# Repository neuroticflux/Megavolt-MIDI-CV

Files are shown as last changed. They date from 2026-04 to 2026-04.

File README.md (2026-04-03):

# Megavolt-MIDI-CV
ATmega328-based modular synth MIDI-CV interface

The Megavolt is a MIDI-CV interface featuring two high quality 12-bit CV outputs for note and pitchbend, four 8-bit CV outputs for MIDI CC's, as well as GATE output, two CLOCK outputs and note glide.

12-bit CVs:
CV 1: MIDI note (with glide amount pot)
CV 2: Pitchbend

MIDI NOTE ON triggers the GATE output HIGH. MIDI NOTE OFF triggers it low.

8-bit CVs:
CV 3: CC #01 (Modwheel)
CV 4: CC #04 (Aftertouch/foot controller)
CV 5: CC #16 (General purpose)
CV 6: Velocity

The two CLOCK jacks output 1/1' and 1/16' ticks the from incoming MIDI clock.

A note stack of 4 notes allows several keys to be held down in succession and released to return to the previous note in the stack, allowing for fast playing of arpeggios etc.

The interface is made to hook up to a PSU delivering +/-15V as well as +5V (Synthesizers.com standard).
Current draw untested.

TODO:

- Eurorack compatibility
- Detect MIDI channel on first incoming message
- Reverse voltage protection diodes on input

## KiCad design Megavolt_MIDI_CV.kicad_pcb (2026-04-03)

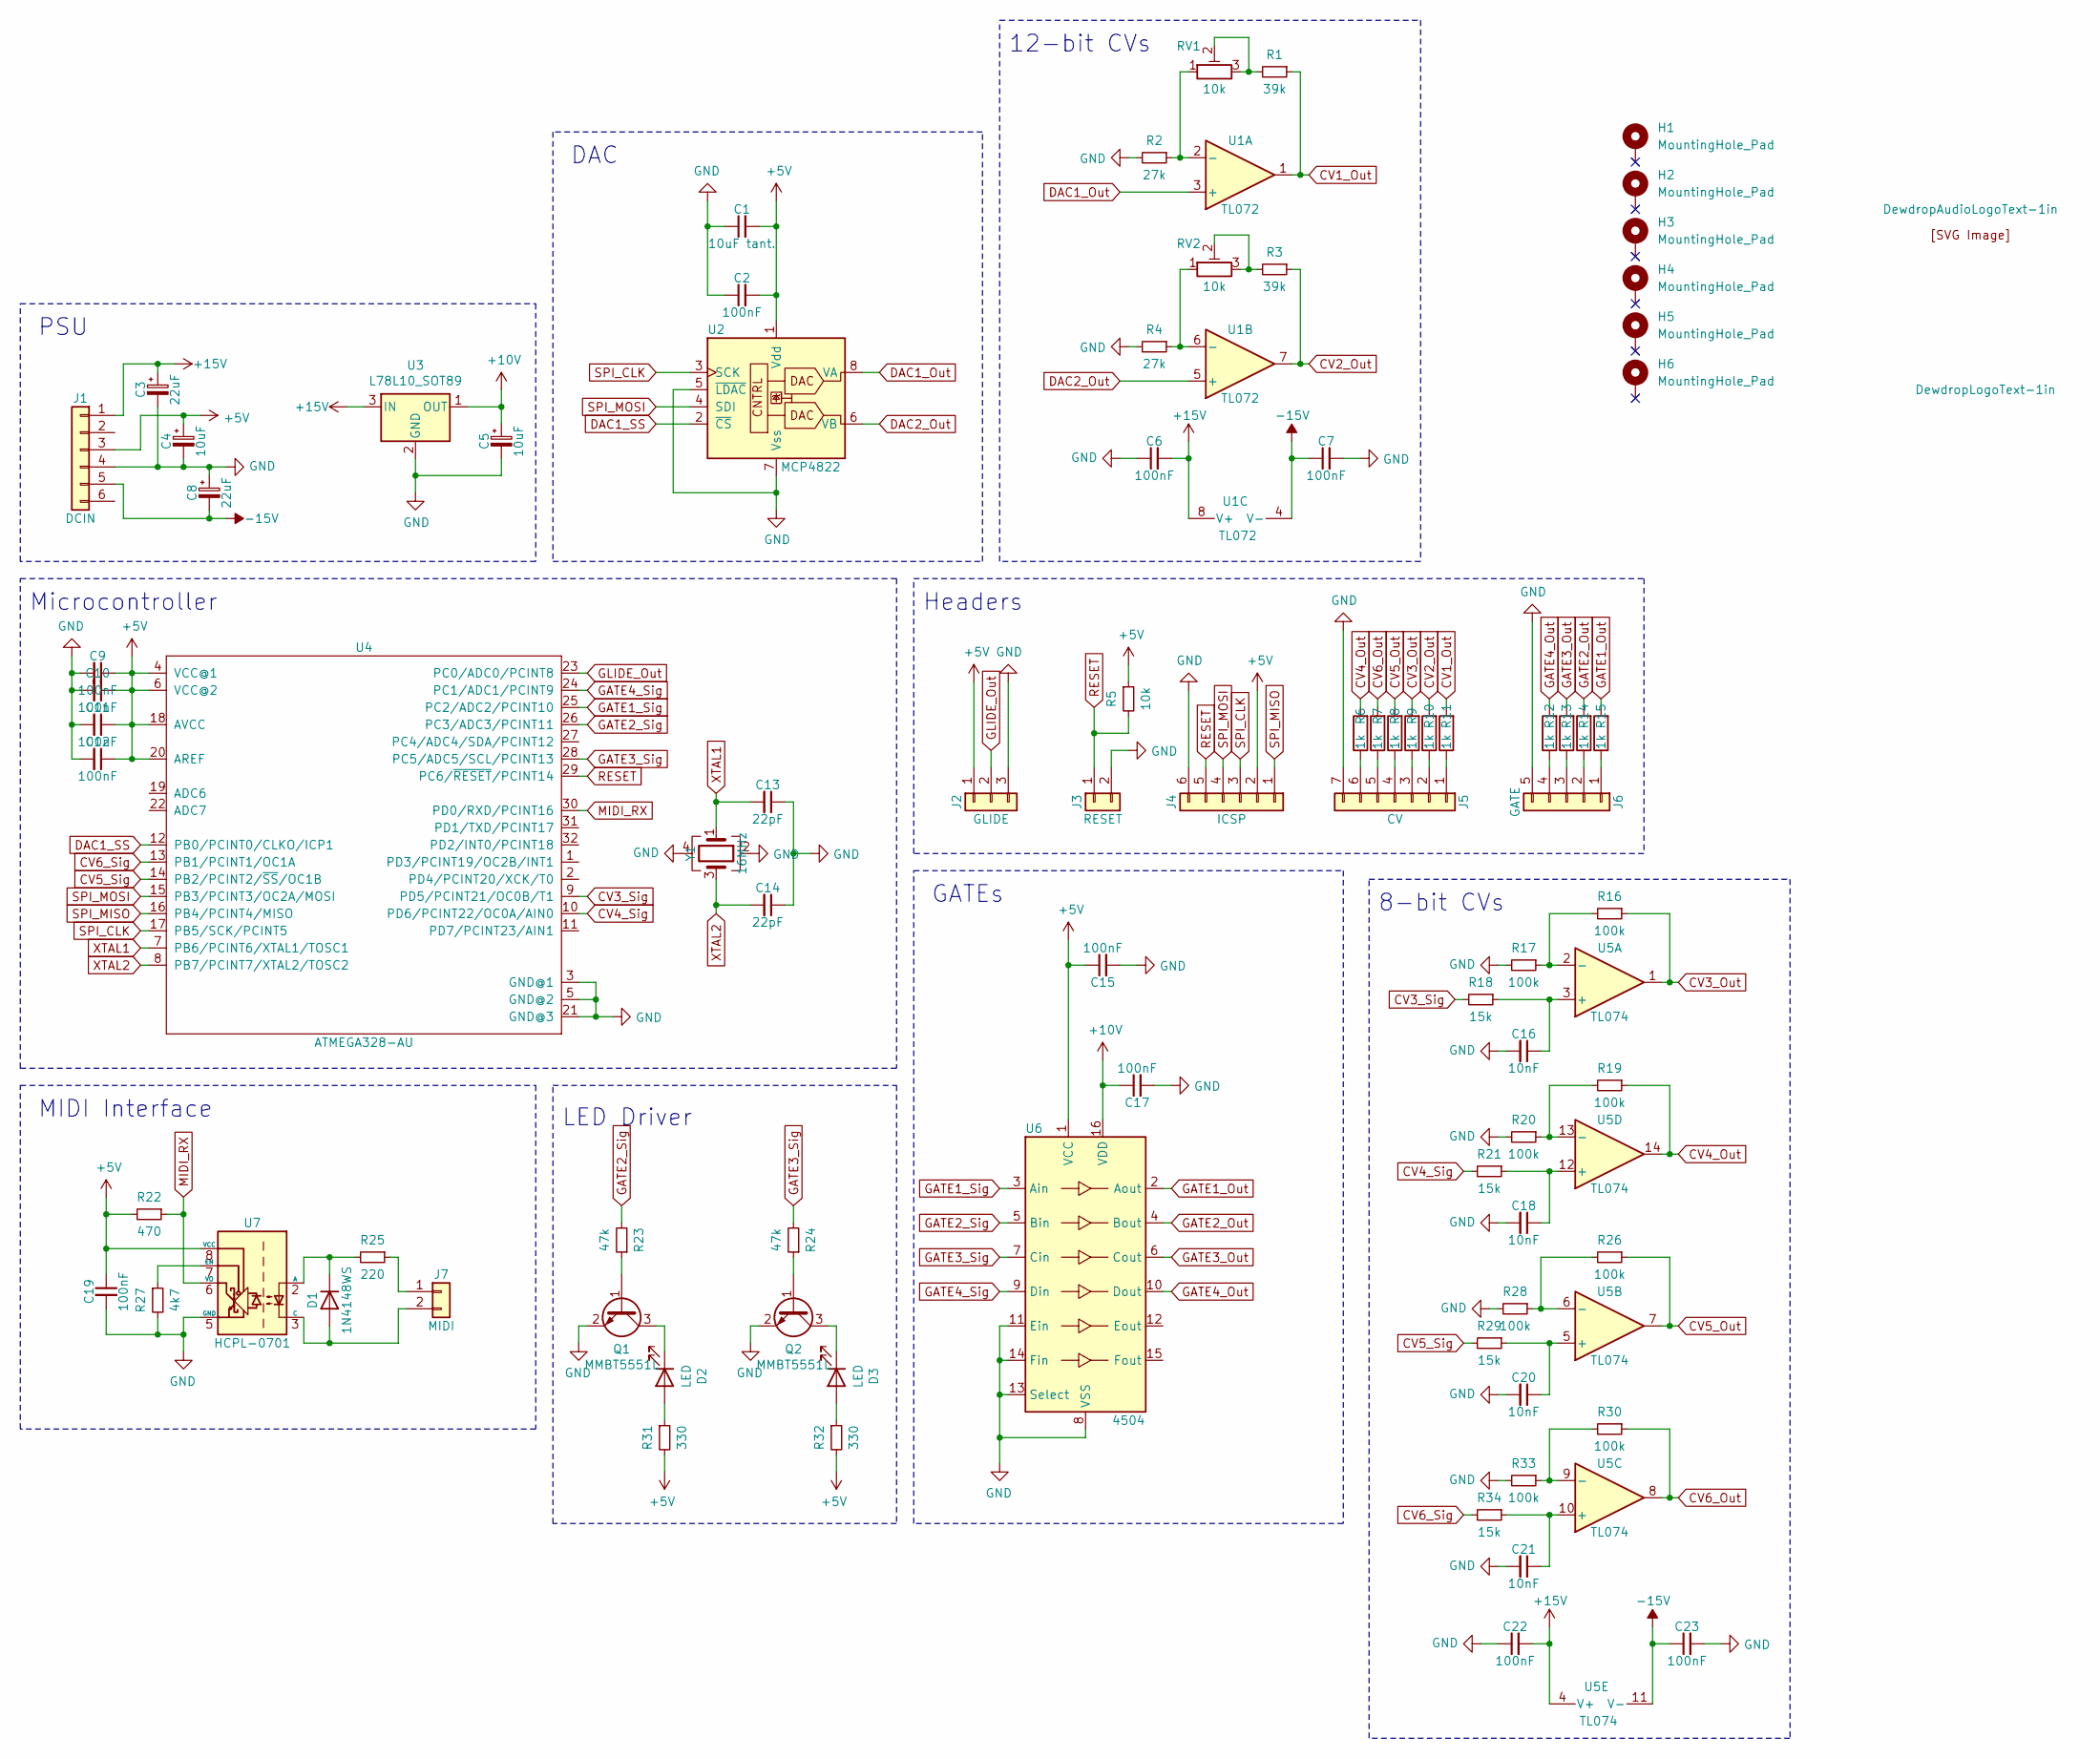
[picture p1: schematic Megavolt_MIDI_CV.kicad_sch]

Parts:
C1: 10uF tant.; CP_EIA-3216-18_Kemet-A
C2, C6, C7, C9, C10, C11, C12, C15, C17, C19, C22, C23: 100nF; C_0603_1608Metric
C3, C8: 22uF; CP_Radial_D5.0mm_P2.50mm
C4, C5: 10uF; CP_Radial_D5.0mm_P2.50mm
C13, C14: 22pF; C_0402_1005Metric
C16, C18, C20, C21: 10nF; C_0603_1608Metric
D1: 1N4148WS; D_SOD-323
D2, D3: LED; PinHeader_1x02_P2.54mm_Vertical
H1, H2, H3, H4, H5, H6: MountingHole_Pad; MountingHole_3.2mm_M3_DIN965_Pad
J1: DCIN; Molex_KK-254_AE-6410-06A_1x06_P2.54mm_Vertical
J2: GLIDE; PinHeader_1x03_P2.54mm_Vertical
J3: RESET; PinHeader_1x02_P2.54mm_Vertical
J4: ICSP; PinHeader_2x03_P2.54mm_Vertical
J5: CV; PinHeader_1x07_P2.54mm_Vertical
J6: GATE; PinHeader_1x05_P2.54mm_Vertical
J7: MIDI; PinHeader_1x02_P2.54mm_Vertical
LOGO2: DewdropLogoText-1in
LOGO3: DewdropAudioLogoText-1in; DewdropAudioLogo-1in
Q1, Q2: MMBT5551L; SOT-23
R1, R3: 39k; R_0402_1005Metric
R2, R4: 27k; R_0402_1005Metric
R5: 10k; R_0402_1005Metric
R6, R7, R8, R9, R10, R11, R12, R13, R14, R15: 1k; R_0603_1608Metric
R16, R17, R19, R20, R26, R28, R30, R33: 100k; R_0402_1005Metric
R18, R21, R29, R34: 15k; R_0402_1005Metric
R22: 470; R_0603_1608Metric
R23, R24: 47k; R_0603_1608Metric
R25: 220; R_0402_1005Metric
R27: 4k7; R_0402_1005Metric
R31, R32: 330; R_0805_2012Metric
RV1, RV2: 10k; Potentiometer_Bourns_3314J_Vertical
U1: TL072; SOIC-8_3.9x4.9mm_P1.27mm
U2: MCP4822; SOIC-8_3.9x4.9mm_P1.27mm
U3: L78L10_SOT89; SOT-89-3
U4: ATMEGA328-AU; LQFP-32_7x7mm_P0.8mm
U5: TL074; SOIC-14_3.9x8.7mm_P1.27mm
U6: 4504; SOIC-16_3.9x9.9mm_P1.27mm
U7: HCPL-0701; SOIC-8_3.9x4.9mm_P1.27mm
Y1: 16MHz; Crystal_SMD_3225-4Pin_3.2x2.5mm

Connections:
+5V: C1.2, C2.2, C4.1, C9.1, C10.1, C11.1, C12.1, C15.1, C19.1, J1.3, J2.1, J4.2, R5.1, R22.2, R31.2, R32.2, U2.1 (Vdd), U4.4 (VCC@1), U4.6 (VCC@2), U4.18 (AVCC), U4.20 (AREF), U6.1 (VCC), U7.8 (VCC)
+10V: C5.1, C17.1, U3.1 (OUT), U6.16 (VDD)
+15V: C3.1, C6.2, C22.2, J1.1, U1.8 (V+), U3.3 (IN), U5.4 (V+)
-15V: C7.1, C8.2, C23.1, J1.5, U1.4 (V-), U5.11 (V-)
CV1_Out: R1.1, R11.2, U1.1
CV2_Out: R3.1, R10.2, U1.7
CV3_Out: R9.2, R16.1, U5.1
CV3_Sig: R18.2, U4.9 (PD5/PCINT21/OC0B/T1)
CV4_Out: R6.2, R19.1, U5.14
CV4_Sig: R21.2, U4.10 (PD6/PCINT22/OC0A/AIN0)
CV5_Out: R8.2, R26.1, U5.7
CV5_Sig: R29.2, U4.14 (PB2/PCINT2/~SS/OC1B)
CV6_Out: R7.2, R30.1, U5.8
CV6_Sig: R34.2, U4.13 (PB1/PCINT1/OC1A)
DAC1_Out: U1.3 (+), U2.8 (VA)
DAC1_SS: U2.2 (~CS), U4.12 (PB0/PCINT0/CLKO/ICP1)
DAC2_Out: U1.5 (+), U2.6 (VB)
GATE1_Out: R15.2, U6.2 (Aout)
GATE1_Sig: U4.25 (PC2/ADC2/PCINT10), U6.3 (Ain)
GATE2_Out: R14.2, U6.4 (Bout)
GATE2_Sig: R23.2, U4.26 (PC3/ADC3/PCINT11), U6.5 (Bin)
GATE3_Out: R13.2, U6.6 (Cout)
GATE3_Sig: R24.2, U4.28 (PC5/ADC5/SCL/PCINT13), U6.7 (Cin)
GATE4_Out: R12.2, U6.10 (Dout)
GATE4_Sig: U4.24 (PC1/ADC1/PCINT9), U6.9 (Din)
GLIDE_Out: J2.2, U4.23 (PC0/ADC0/PCINT8)
GND: C1.1, C2.1, C3.2, C4.2, C5.2, C6.1, C7.2, C8.1, C9.2, C10.2, C11.2, C12.2, C13.1, C14.1, C15.2, C16.2, C17.2, C18.2, C19.2, C20.2, C21.2, C22.1, C23.2, J1.4, J2.3, J3.2, J4.6, J5.7, J6.5, Q1.2 (E), Q2.2 (E), R2.2, R4.2, R17.2, R20.2, R27.2, R28.2, R33.2, U2.5 (~LDAC), U2.7 (Vss), U3.2 (GND), U4.3 (GND@1), U4.5 (GND@2), U4.21 (GND@3), U6.8 (VSS), U6.11 (Ein), U6.13 (Select), U6.14 (Fin), U7.5 (GND), Y1.2, Y1.4
MIDI_RX: R22.1, U4.30 (PD0/RXD/PCINT16), U7.6 (VO)
unnamed: D1.2 (A), J7.2, U7.3 (C)
unnamed: D1.1 (K), R25.2, U7.2 (A)
unnamed: D2.2 (A), R31.1
unnamed: D2.1 (K), Q1.3 (C)
unnamed: D3.2 (A), R32.1
unnamed: D3.1 (K), Q2.3 (C)
unnamed: J5.1, R11.1
unnamed: J5.2, R10.1
unnamed: J5.3, R9.1
unnamed: J5.4, R8.1
unnamed: J5.5, R7.1
unnamed: J5.6, R6.1
unnamed: J6.1, R15.1
unnamed: J6.2, R14.1
unnamed: J6.3, R13.1
unnamed: J6.4, R12.1
unnamed: J7.1, R25.1
unnamed: Q1.1 (B), R23.1
unnamed: Q2.1 (B), R24.1
unnamed: R1.2, RV1.2, RV1.3
unnamed: R3.2, RV2.2, RV2.3
unnamed: R2.1, RV1.1, U1.2 (-)
unnamed: R4.1, RV2.1, U1.6 (-)
unnamed: C16.1, R18.1, U5.3 (+)
unnamed: R16.2, R17.1, U5.2 (-)
unnamed: C20.1, R29.1, U5.5 (+)
unnamed: R26.2, R28.1, U5.6 (-)
unnamed: C21.1, R34.1, U5.10 (+)
unnamed: R30.2, R33.1, U5.9 (-)
unnamed: C18.1, R21.1, U5.12 (+)
unnamed: R19.2, R20.1, U5.13 (-)
unnamed: R27.1, U7.7 (EN)
RESET: J3.1, J4.5, R5.2, U4.29 (PC6/~RESET/PCINT14)
SPI_CLK: J4.3, U2.3 (SCK), U4.17 (PB5/SCK/PCINT5)
SPI_MISO: J4.1, U4.16 (PB4/PCINT4/MISO)
SPI_MOSI: J4.4, U2.4 (SDI), U4.15 (PB3/PCINT3/OC2A/MOSI)
XTAL1: C13.2, U4.7 (PB6/PCINT6/XTAL1/TOSC1), Y1.1
XTAL2: C14.2, U4.8 (PB7/PCINT7/XTAL2/TOSC2), Y1.3

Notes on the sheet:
Headers
8-bit CVs
Microcontroller
GATEs
DAC
LED Driver
12-bit CVs
MIDI Interface
PSU

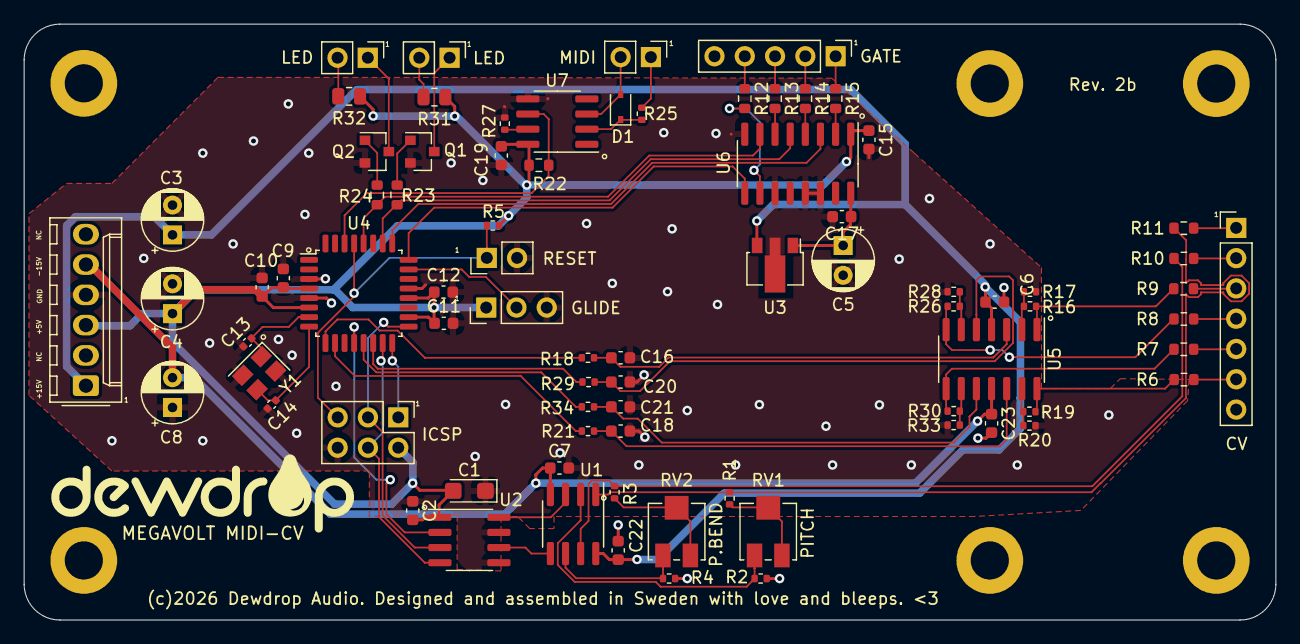
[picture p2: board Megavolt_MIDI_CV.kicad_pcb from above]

Board: 2 copper layers, 105.0 x 50.0 mm, 87 parts (1 on the bottom side), 66 nets.

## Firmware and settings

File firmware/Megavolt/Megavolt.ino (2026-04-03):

#include "Arduino.h"

#include <SPI.h>
#include <MIDI.h>

#define REFERENCE_FREQUENCY 2000 // Desired update frequency in Hz

#define INVALID_NOTE 128
#define NOTE_MEM_SIZE 4

// Precalc timer settings
#define TIMER_COUNT F_CPU / REFERENCE_FREQUENCY
#define PRESCALE_VALUE 32

// DAC settings
#define DAC_GAIN_2X 0
#define DAC_GAIN_1X 1
#define DAC_CHANNEL_A 0
#define DAC_CHANNEL_B 1

// MIDI Controller #
#define MIDI_CC_MODWHEEL 1
#define MIDI_CC_AFTERTOUCH 4
struct dac_cv
{
	int32_t target = 0;
	int32_t current = 0;
};

// DAC CV (12-bit) outs
dac_cv CV_1, CV_2;

// PWM CV (8-bit) outs
#define CV_3 OCR1A // ATmega pin 15
#define CV_4 OCR0A // ATmega pin 12
#define CV_5 OCR1B // ATmega pin 16
#define CV_6 OCR0B // ATmega pin 11

#define CV_VELOCITY CV_3
#define CV_ATOUCH CV_4
#define CV_MODWHEEL CV_5
#define CV_CUSTOM CV_6

// Gates
#define GATE_BIT 0x08 // GATE
#define CLOCK_BIT 0x20 // 1/1'
#define CLOCK16_BIT 0x04 // 1/16'

#define DAC_SS_BIT 0x02

uint8_t note_list[NOTE_MEM_SIZE];
int8_t num_playing_notes = 0;
uint8_t clock_counter = 0;
uint8_t midi_channel = 0; // TODO: Make this adjustable, auto-detect on first incoming note?
uint8_t glide_amount = 0;
int16_t bend = 0;

uint8_t playing = 0;

MIDI_CREATE_DEFAULT_INSTANCE();

void setup()
{
	// DAC SS pin
	pinMode(8, OUTPUT);

	// GATE outputs
  pinMode(A0, INPUT);
	pinMode(A1, OUTPUT);
	pinMode(A2, OUTPUT);
	pinMode(A3, OUTPUT);
  pinMode(A5, OUTPUT);

	MIDI.setHandleNoteOn(midi_note_on);
	MIDI.setHandleNoteOff(midi_note_off);
	MIDI.setHandleClock(midi_clock);
  MIDI.setHandleStart(midi_start);
  MIDI.setHandleStop(midi_stop);
	MIDI.setHandleControlChange(midi_cc);
	MIDI.setHandlePitchBend(midi_pitchbend);

	MIDI.begin(0);

	SPI.begin();

	//TIMER0: (PWM CV outputs)
	pinMode(5, OUTPUT);
	pinMode(6, OUTPUT);

	TCCR0A = 0; // Reset register

	TCCR0A = _BV(COM0A1) | _BV(COM0B1) | _BV(WGM00) | _BV(WGM01);
	TCCR0B = _BV(CS00);

	OCR0A = 0;
	OCR0B = 0;

	//TIMER1: (PWM CV outputs)
	pinMode(9, OUTPUT);
	pinMode(10, OUTPUT);

	TCCR1A = 0;
	TCCR1B = 0;

	TCCR1A = _BV(COM1A1) | _BV(COM1B1) | _BV(WGM10);
	TCCR1B = _BV(WGM12) | _BV(CS10);

	OCR1A = 0;
	OCR1B = 0;

	//TIMER2: (Logic/update)

	TCCR2A = 0; // Reset register
	TCCR2B = 0;

	// Set CTC mode
	TCCR2A = _BV(WGM21);
	TCCR2B = _BV(CS20) | _BV(CS21);

	// Set Timer2 timeout
	OCR2A = (TIMER_COUNT / PRESCALE_VALUE) - 1;

	TCNT2 = 0; // Reset counter

	TIMSK2 =_BV(OCIE2A); // Enable timer compare interrupt

//	OCR2A = 255; // Set CTC
//	OCR2B = 64; // Set PWM duty cycle

	num_playing_notes = 0;

  // Set CV_2 (pitchbend) to default midrange value
  CV_2.target = CV_2.current = 2048;
}

void midi_start()
{
  playing = 1;
  clock_counter = 24; // Initialize the counter on the first beat
  num_playing_notes = 0;
  // Make sure gates are off
  PORTC &= ~CLOCK_BIT;
  PORTC &= ~CLOCK16_BIT;
  PORTC &= ~GATE_BIT;
}

void midi_stop()
{
  playing = 0;
  // Reset clock counter and note memory
  num_playing_notes = 0;
  clock_counter = 0;

  // Turn off gates
  PORTC &= ~CLOCK_BIT;
  PORTC &= ~CLOCK16_BIT;
  PORTC &= ~GATE_BIT;
}

void midi_note_on(byte channel, byte note, byte velocity)
{
  // Auto-detect channel on first incoming note and set it,
  // then ignore messages on other channels
  if(midi_channel != channel) {
    if(midi_channel == 0) {
      midi_channel = channel;
    } else {
      return;
    }
  }
	CV_VELOCITY = velocity << 1;
	PORTC |= GATE_BIT;
  
  note_list[num_playing_notes++] = note;
  
	CV_1.target = uint32_t(note) << 24; // Convert 7-bit MIDI message to 32-bit internal format

   // Reset glide if no notes were playing
  if (num_playing_notes == 1) {
    CV_1.current = CV_1.target;
  }
};

void midi_note_off(byte channel, byte note, byte velocity)
{
  uint8_t found = 0;
  
  // Find the note that was turned off
  for (int i = 0; i < num_playing_notes; i++) {
    if (note_list[i] == note) {
      found = 1;
    }
    // We found the note, so move everything above it down by one.
    if (found && i < num_playing_notes - 1) {
      note_list[i] = note_list[i + 1];
    }
  }
  num_playing_notes--;

  // Play the top note in list
  if (num_playing_notes > 0) {
    CV_1.target = uint32_t(note_list[num_playing_notes - 1]) << 24;
  } 

  // Turn GATE off
  else if (num_playing_notes <= 0)
	{
		num_playing_notes = 0;
		PORTC &= ~GATE_BIT;
	}
}

void midi_cc(byte channel, byte CC, byte value)
{
	if (channel == midi_channel && CC == MIDI_CC_MODWHEEL)
		CV_MODWHEEL = value << 1;
	else if (channel == midi_channel && CC == MIDI_CC_AFTERTOUCH)
		CV_ATOUCH = value << 1;
}

// NOTE: MIDI sends 24 clock pulses per quarter note. That's 6 pulses per 16th, or 96 pulses per beat
void midi_clock()
{
  // The midi_start() callback starts at 24, so the first tick is on the first beat
   
  // If we've counted 24 pulses (1/4th note), toggle the clock pin high for the next pulse
	if (clock_counter % 24 == 0 && playing) {
		PORTC |= CLOCK_BIT;
    clock_counter = 0;
  // Keep the pin normally low
  } else {
    PORTC &= ~CLOCK_BIT;
  }

  // If we've counted a 16th (every 6 pulses), toggle the 16th pin high for the next pulse
  if (clock_counter % 6 == 0 && playing) {
    // TODO: Toggle 16th pin
    PORTC |= CLOCK16_BIT;
  }
  else {
    // TODO: Keep the 16th pin normally low
    PORTC &= ~CLOCK16_BIT;
  }

  clock_counter++;
}

//NOTE: Pitchbend range is -8192 -> 8191 (14-bit MIDI message)
void midi_pitchbend(byte channel, int value)
{
	CV_2.target = (value + 8192) >> 2; // Make unsigned and shift to 12-bit for DAC out
	bend = value >> 6; // Shift to 8-bit internal resolution (for reasonable pbend range)
}

// TODO/IDEA: DAC config for each channel could be held in a variable and OR:ed with the data instead of all these shifts every tick?
inline void write_dac(uint16_t value, uint8_t channel)
{
	PORTB &= ~B00000001; // Set SS pin low
	SPI.transfer16(((channel << 7 | DAC_GAIN_2X << 5 | 1 << 4) << 8) | value);
	PORTB |= B00000001; // Set SS pin high
}

// TODO: Profile ISR, it needs to work at a few KHz at least
ISR(TIMER2_COMPA_vect) // 2KHz update freq.
{
  // TODO: HW switch for bend applied to pitch
	write_dac((CV_1.current >> 19)/* + bend */,  DAC_CHANNEL_A); // Shift back to 12 bits for DAC output and add pitchbend
	write_dac(CV_2.target, DAC_CHANNEL_B);

	// Do note glide
  int32_t glide = 1 + (analogRead(A0) << 4);
  CV_1.current += (CV_1.target - CV_1.current) / glide;
}

void loop()
{
	MIDI.read();
}

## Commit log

2018-03-25 v2 board update
2020-11-26 Rev.1a board + schematic
2022-11-19 Rev.2 files, update to KiCad6
    [Megavolt Rev2.kicad_pcb, Megavolt Rev2.kicad_sch, Megavolt Rev2.sch]
2022-12-17 Firmware bugfixes, Rev.2 board compatibility
    [Megavolt.ino]
2022-12-19 Auto-detect MIDI channel, pitch bend on CV2 out, bugfixes
    [Megavolt.ino]
2022-12-25 Rev.3 WIP
    [Megavolt Rev2.kicad_pcb, Megavolt Rev2.kicad_sch]
2026-04-03 Removed old project, updated to Rev. 2b
    [Megavolt Rev2.kicad_pcb, Megavolt Rev2.kicad_sch, Megavolt Rev2.sch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]

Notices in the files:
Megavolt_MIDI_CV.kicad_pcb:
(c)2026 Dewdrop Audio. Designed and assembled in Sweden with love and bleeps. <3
